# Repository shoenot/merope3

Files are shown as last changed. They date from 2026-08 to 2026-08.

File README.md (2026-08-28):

# Merope
## 68 key split mechanical keyboard

Merope is a split mechanical keyboard design based vaguely off the lily58 and other common split keyboards. This one has what I consider to be a pretty agressive colstag. 
There are 7 main columns of 4 rows (for basically 60% coverage), plus 2 mod row keys, 3 thumb cluster keys, and an inner key above the thumb cluster. Key layout and pictures TBA after I get my hands on everything (PCB currently being fabbed)

Don't have an ergogen as I did the whole thing in KiCad, but here's how the plate looks: 

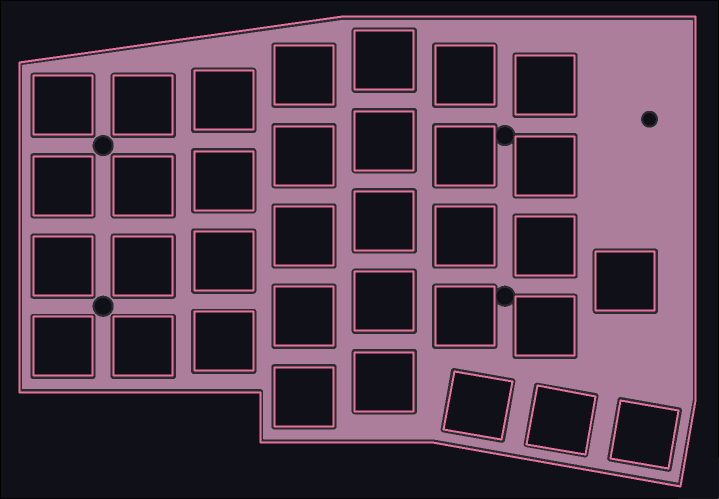
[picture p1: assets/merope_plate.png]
merope_plate


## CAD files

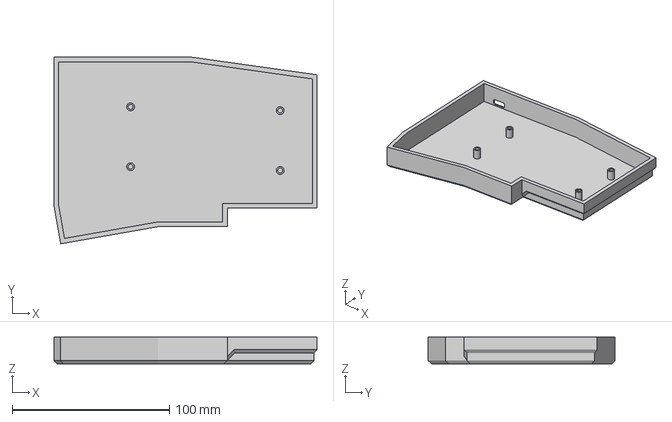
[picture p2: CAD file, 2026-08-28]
case/merope_tray_mount_case_right.3mf
167.5 x 118.9 x 17.0 mm

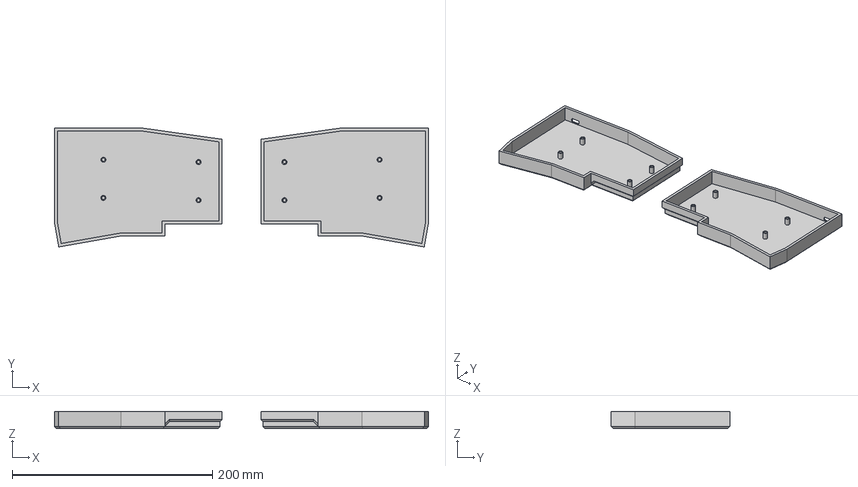
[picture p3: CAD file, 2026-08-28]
case/merope_tray_mount_case.step
373.9 x 118.9 x 17.0 mm

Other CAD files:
case/merope_tray_mount_case.3mf

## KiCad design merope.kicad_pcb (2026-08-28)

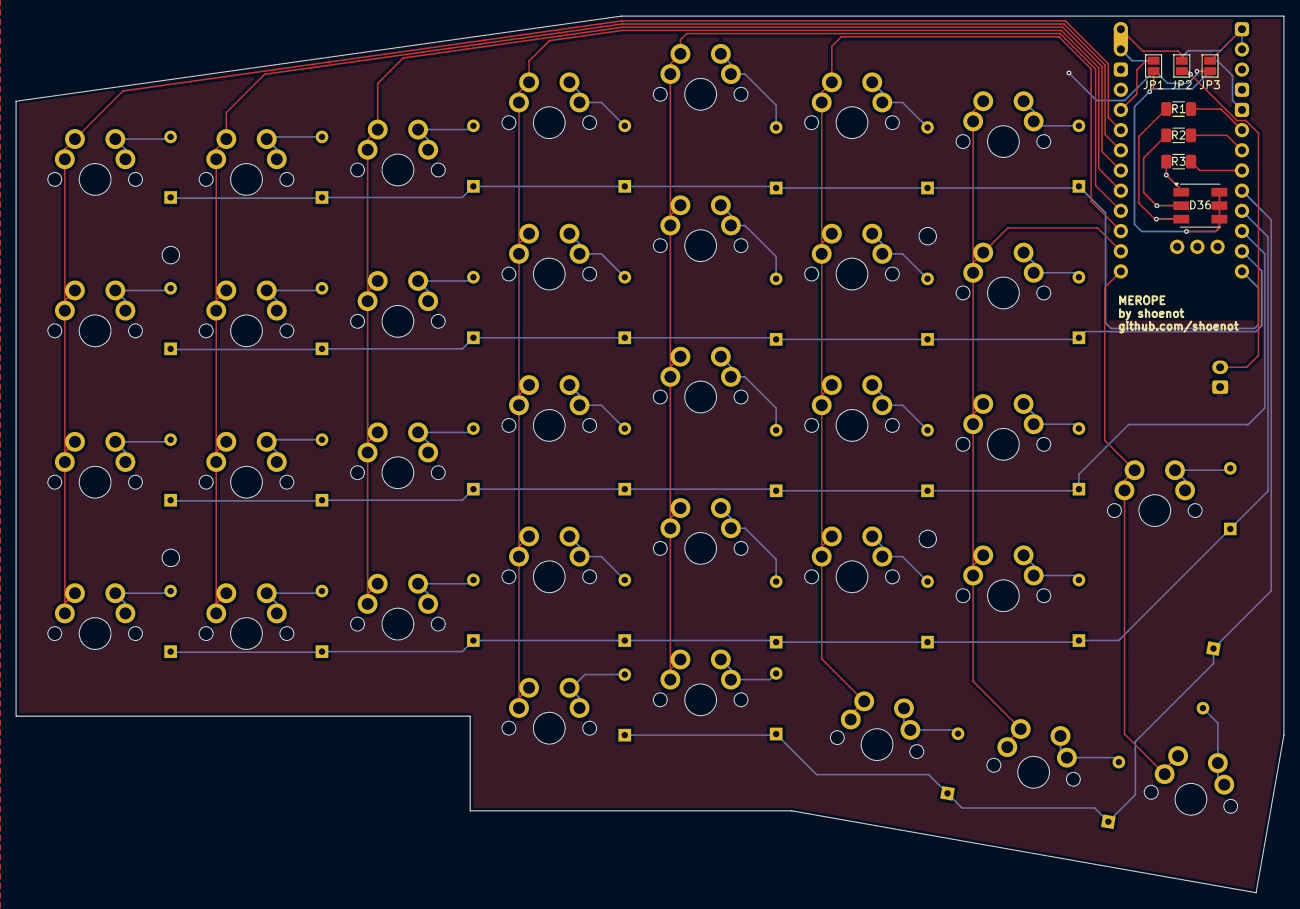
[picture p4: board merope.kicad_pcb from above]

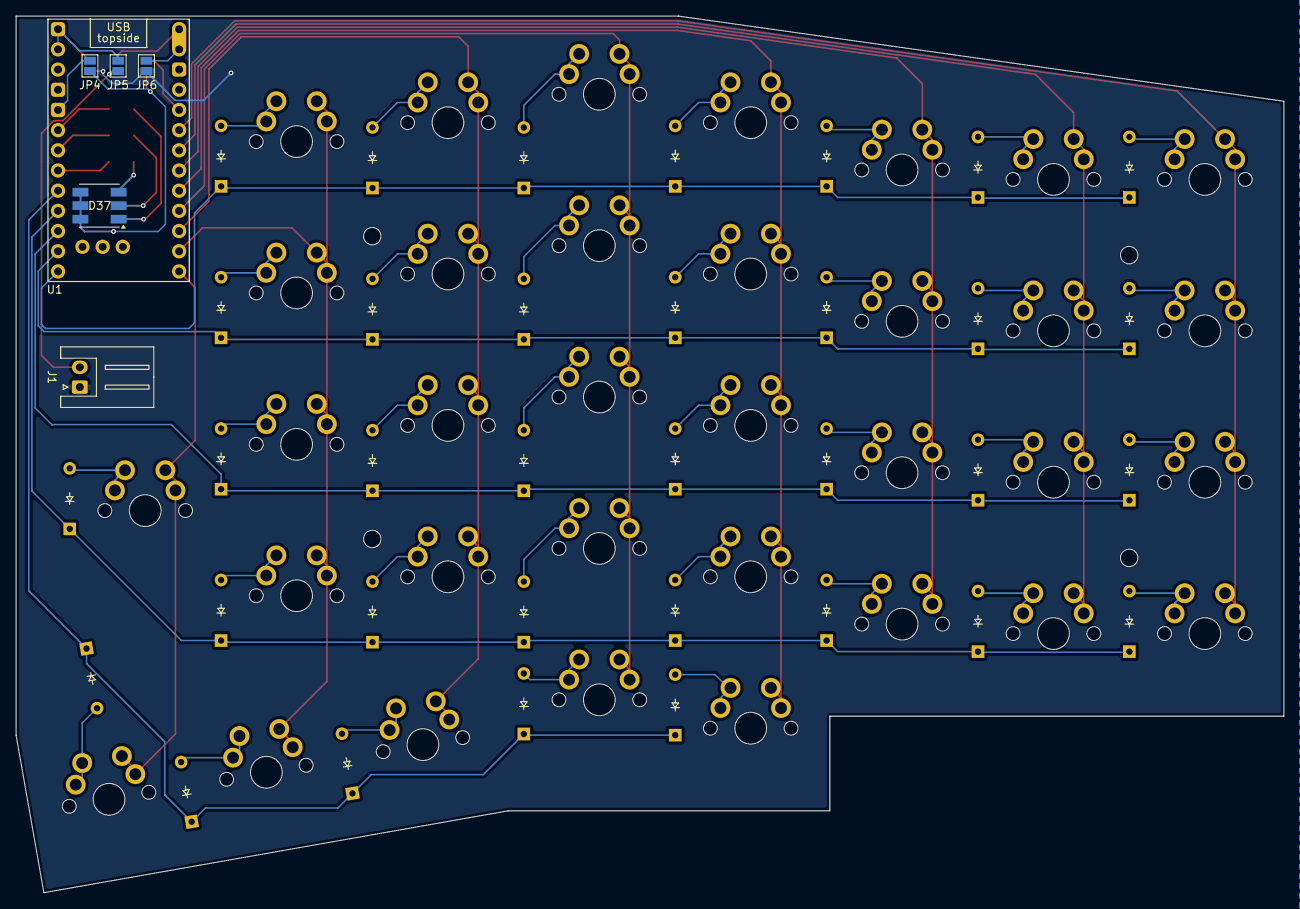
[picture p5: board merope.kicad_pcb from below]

Board: 2 copper layers, 159.5 x 110.3 mm, 81 parts (40 on the bottom side), 60 nets.

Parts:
D1, D2, D3, D4, D5, D6, D7, D8, D9, D10, D11, D12, D13, D14, D15, D16, D17, D18, D19, D20, D21, D22, D23, D24, D25, D26, D27, D28, D29, D31, D32, D33, D34, D35: D; Diode_DO-35
D36, D37: LED_RGB; LED_RGB_5050-6
J1: Conn_01x02_Socket; JST_XH_S2B-XH-A_1x02_P2.50mm_Horizontal
JP1: 3V3 SIDE A; SolderJumper-2_P1.3mm_Open_Pad1.0x1.5mm
JP2: PWR SIDE A; SolderJumper-2_P1.3mm_Open_Pad1.0x1.5mm
JP3: GND SIDE A; SolderJumper-2_P1.3mm_Open_Pad1.0x1.5mm
JP4: 3V3 SIDE B; SolderJumper-2_P1.3mm_Open_Pad1.0x1.5mm
JP5: PWR SIDE B; SolderJumper-2_P1.3mm_Open_Pad1.0x1.5mm
JP6: GND SIDE B; SolderJumper-2_P1.3mm_Open_Pad1.0x1.5mm
R1, R2, R3: R_Small_US; R_1206_3216Metric_Pad1.30x1.75mm_HandSolder
SW1, SW2, SW3, SW4, SW5, SW6, SW7, SW8, SW9, SW10, SW11, SW12, SW13, SW14, SW15, SW16, SW17, SW18, SW19, SW20, SW21, SW22, SW23, SW24, SW25, SW26, SW27, SW28, SW29, SW30, SW31, SW32, SW33, SW34: SW_Push; MX_Solder_1.00u_Reversible
U1: SuperMini nRF52840; SuperMini_nRF52840_AH_USBup

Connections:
/3V3: D36.4 (BA), D36.5 (GA), D36.6 (RA), D37.4 (BA), D37.5 (GA), D37.6 (RA), JP1.2 (B), JP4.2 (B)
/3V3 MAIN: JP1.1 (A), U1.16 (3V3)
/3v3 REV: JP4.1 (A), U1.4 (GND)
/BAT MAIN: JP2.1 (A), JP6.1 (A), U1.13 (BAT+), U1.29 (BAT+)
/BAT REV: JP3.1 (A), JP5.1 (A), U1.1 (P0.06), U1.28 (GND)
/GND: J1.1, JP3.2 (B), JP6.2 (B)
/LED1: R3.2, U1.7 (P0.22)
/LED2: R2.2, U1.6 (P0.20)
/LED3: R1.2, U1.5 (P0.17)
/LED_R1: D36.1 (RK), D37.3 (BK), R3.1
/LED_R2: D36.2 (GK), D37.2 (GK), R2.1
/LED_R3: D36.3 (BK), D37.1 (RK), R1.1
/PWR: J1.2, JP2.2 (B), JP5.2 (B)
COL0: SW1.1, SW8.1, SW15.1, SW22.1, U1.17 (P0.31-LF)
COL1: SW2.1, SW9.1, SW16.1, SW23.1, U1.18 (P0.29-LF)
COL2: SW3.1, SW10.1, SW17.1, SW24.1, U1.19 (P0.02-LF)
COL3: SW4.1, SW11.1, SW18.1, SW25.1, SW30.1, U1.20 (P1.15-LF)
COL4: SW5.1, SW12.1, SW19.1, SW26.1, SW31.1, U1.21 (P1.13-LF)
COL5: SW6.1, SW13.1, SW20.1, SW27.1, SW32.1, U1.22 (P1.11-LF)
COL6: SW7.1, SW14.1, SW21.1, SW28.1, SW33.1, U1.23 (P0.10-LF)
COL7: SW29.1, SW34.1, U1.24 (P0.09-LF)
unnamed: D1.2 (A), SW1.2
unnamed: D2.2 (A), SW2.2
unnamed: D3.2 (A), SW3.2
unnamed: D4.2 (A), SW4.2
unnamed: D5.2 (A), SW5.2
unnamed: D6.2 (A), SW6.2
unnamed: D7.2 (A), SW7.2
unnamed: D8.2 (A), SW8.2
unnamed: D9.2 (A), SW9.2
unnamed: D10.2 (A), SW10.2
unnamed: D11.2 (A), SW11.2
unnamed: D12.2 (A), SW12.2
unnamed: D13.2 (A), SW13.2
unnamed: D14.2 (A), SW14.2
unnamed: D15.2 (A), SW15.2
unnamed: D16.2 (A), SW16.2
unnamed: D17.2 (A), SW17.2
unnamed: D18.2 (A), SW18.2
unnamed: D19.2 (A), SW19.2
unnamed: D20.2 (A), SW20.2
unnamed: D21.2 (A), SW21.2
unnamed: D22.2 (A), SW22.2
unnamed: D23.2 (A), SW23.2
unnamed: D24.2 (A), SW24.2
unnamed: D25.2 (A), SW25.2
unnamed: D26.2 (A), SW26.2
unnamed: D27.2 (A), SW27.2
unnamed: D28.2 (A), SW28.2
unnamed: D29.2 (A), SW29.2
unnamed: D31.2 (A), SW30.2
unnamed: D32.2 (A), SW31.2
unnamed: D33.2 (A), SW32.2
unnamed: D34.2 (A), SW33.2
unnamed: D35.2 (A), SW34.2
ROW0: D1.1 (K), D2.1 (K), D3.1 (K), D4.1 (K), D5.1 (K), D6.1 (K), D7.1 (K), U1.12 (P1.06-LF)
ROW1: D8.1 (K), D9.1 (K), D10.1 (K), D11.1 (K), D12.1 (K), D13.1 (K), D14.1 (K), U1.11 (P1.04-LF)
ROW2: D15.1 (K), D16.1 (K), D17.1 (K), D18.1 (K), D19.1 (K), D20.1 (K), D21.1 (K), U1.10 (P0.11)
ROW3: D22.1 (K), D23.1 (K), D24.1 (K), D25.1 (K), D26.1 (K), D27.1 (K), D28.1 (K), D29.1 (K), U1.9 (P1.00)
ROW4: D31.1 (K), D32.1 (K), D33.1 (K), D34.1 (K), D35.1 (K), U1.8 (P0.24)

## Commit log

2026-08-25 almost final
    [merope3-Edge_Cuts.dxf, merope3-User_1.dxf, merope3.kicad_pcb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]
2026-08-28 final v1.0
    [designators.csv, merope3.kicad_pcb, merope3_plate.kicad_pcb]
2026-08-28 repo restructure
    [designators.csv, merope.kicad_pcb, merope.kicad_sch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]
